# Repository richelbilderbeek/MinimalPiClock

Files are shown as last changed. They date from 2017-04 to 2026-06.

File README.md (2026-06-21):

# Minimal Pi Clock

<!-- markdownlint-disable MD013 --><!-- Table rows must be put on one line, hence 80 chars is unavoidable -->






<!-- markdownlint-enable MD013 -->

[Go to our nicely rendered website](https://richelbilderbeek.github.io/minimal_pi_clock/).

- [Contributing](docs/CONTRIBUTING.md)

## Files used by continuous integration scripts

<!-- markdownlint-disable MD013 --><!-- Table rows must be put on one line, hence 80 chars is unavoidable -->

Filename                                    |Descriptions
--------------------------------------------|--------------------------------------------------------------------------------------------------------------------------------------
[`mlc_config.json`](mlc_config.json)        |Configuration of the link checker, use `markdown-link-check --config mlc_config.json --quiet docs/**/*.md` to do link checking locally
[`.markdownlint.jsonc`](.markdownlint.jsonc)|Configuration of the Markdown linter, use `markdownlint "**/*.md"` to do markdown linting locally. The name of this file is a default name.
[`.markdownlintignore`](.markdownlintignore)|Files ignored by the Markdown linter, use `markdownlint "**/*.md"` to do markdown linting locally. The name of this file is a default name.

<!-- markdownlint-enable MD013 -->

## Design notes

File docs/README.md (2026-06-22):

# Minimal Pi Clock

The Minimal Pi Clock is
[one of my machines](https://github.com/richelbilderbeek/Machines)
that uses (the programmable chip of an) Arduino.

It's an Arduino project for a clock that beeps at pi o'clock PM
(i.e. 3:14 PM or 15:14). It can easily be made to beep at 3:14 AM
for the purists :-)

- [Photos](photos/README.md)
- [Parts list](parts_list/README.md)
- [Code](src/README.md)
- [Schematic](schematic/README.md)
- [Casing](casing/README.md)
- [FAQ](faq.md)

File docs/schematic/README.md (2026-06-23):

# Schematics

- [The Fritzing file](minimal_pi_clock.fzz)

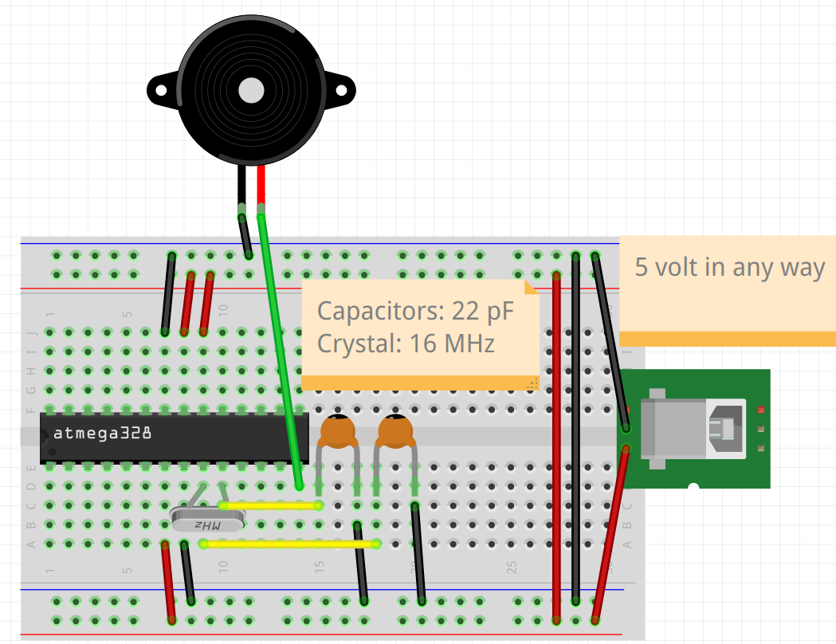
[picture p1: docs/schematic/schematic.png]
The Minimal Pi Clock schematic


Build the schematic as such,
using the chip with The Minimal Pi Clock
program on it.

??? question "In which orientation must I have the chip?"

    The notch of the chip must be at the left:

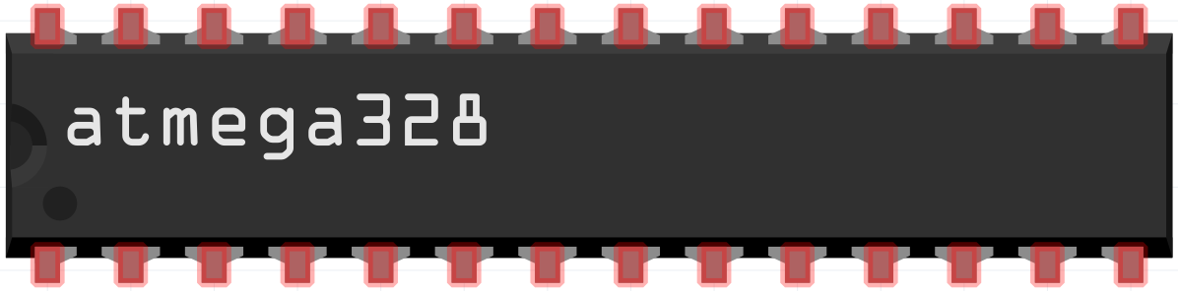
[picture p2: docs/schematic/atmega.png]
The notch of the chip must be at the left
    

    > The notch of the chip must be at the left.

??? question "Can you show the wiring of the chip as a table?"

    Yes.

    Here is an equivalent table:

    Pin  |1  |2  |3  |4  |5  |6  |7  |8  |9  |10 |11 |12 |13 |14
    -----|---|---|---|---|---|---|---|---|---|---|---|---|---|---
    Upper|.  |.  |.  |.  |.  |.  |GND|5V |5V |.  |.  |.  |.  |.
    Lower|.  |.  |.  |.  |.  |.  |5V |GND|X1 |X2 |.  |.  |.  |P

    - `GND`: to ground
    - `5V`: to 5 volt
    - `X1`: to a capacitor and crystal
    - `X2`: to (another) capacitor and (the same) crystal
    - `P`: to plus of piezo

??? question "What does '5 Volts in any way' mean?"

    Where the schematic states '5 Volts in any way',
    this means any reasonable way to provide 5 volts
    for the machine.

    In this example, a USB-B female is shown,
    but any USB connector can be used.

??? question "Can I use other electric potenials than 5V?"

    Yes.

    The range of the chip is wider than 5 volts.

Upon powering this, the buzzer will go off for
a little more than three seconds.

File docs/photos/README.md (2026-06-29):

# Minimal Pi Clock pictures

The Minimal Pi Clock can look many different ways.

## 2017

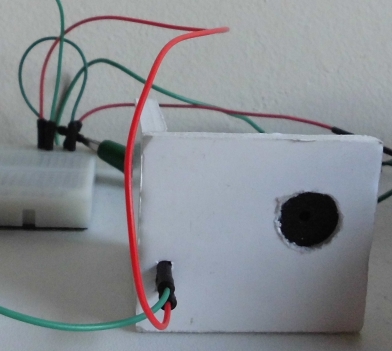
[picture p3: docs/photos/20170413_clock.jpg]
Minimal Pi Clock in 2017, full picture


> Minimal Pi Clock, front view. The machine was powered by the Arduino
> 5V and GND pins.

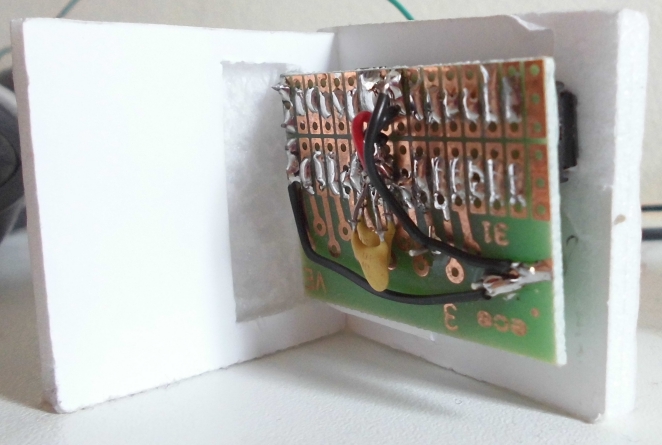
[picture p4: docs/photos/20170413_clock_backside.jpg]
Minimal Pi Clock in 2017, backside view


> Minimal Pi Clock, back view

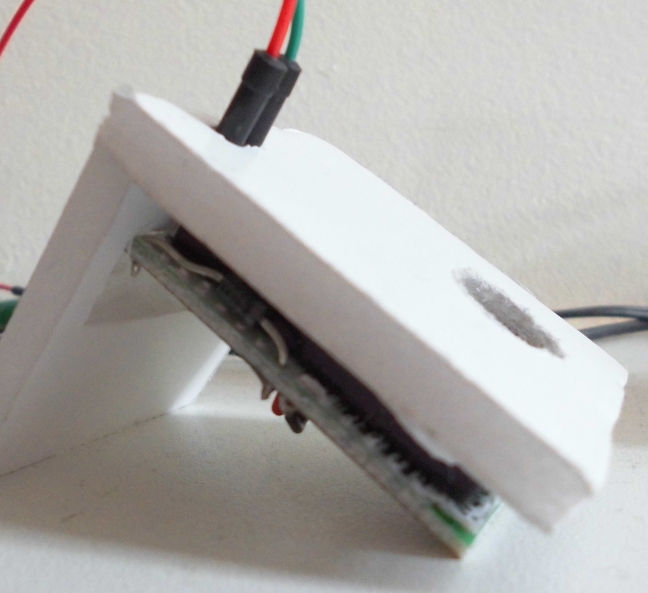
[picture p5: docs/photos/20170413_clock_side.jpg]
Minimal Pi Clock in 2017, side view


> Minimal Pi Clock, side view

## 2019

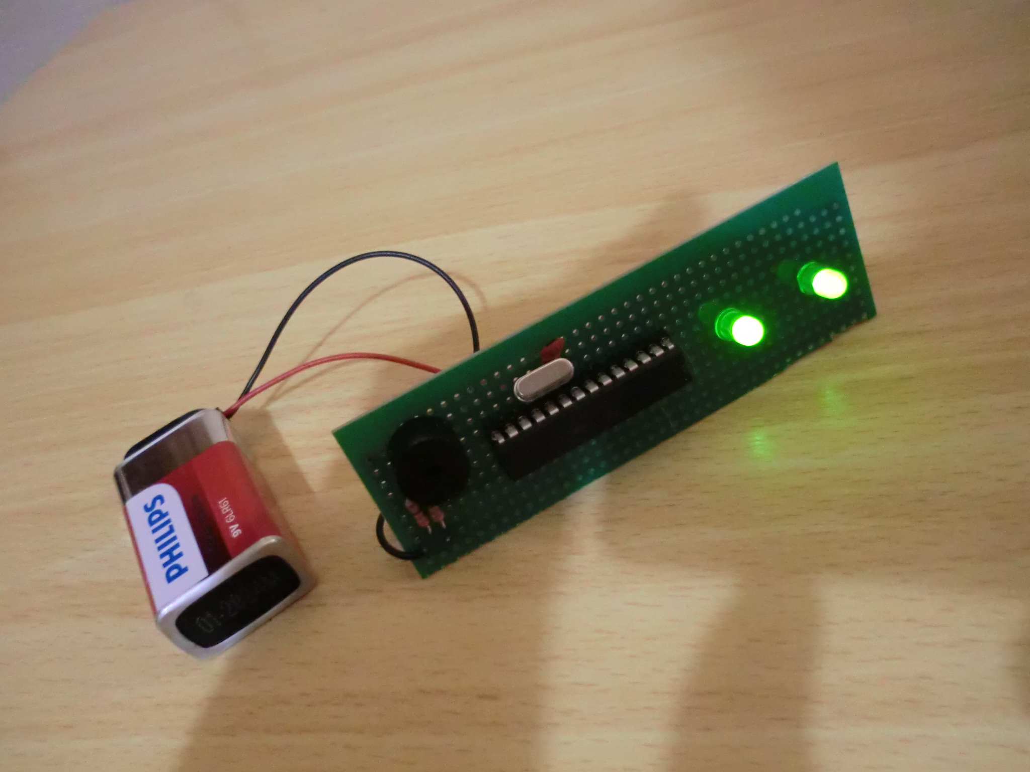
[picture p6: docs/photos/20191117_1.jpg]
Minimal Pi Clock in 2019, PCB front view


> PCB is ready, front view

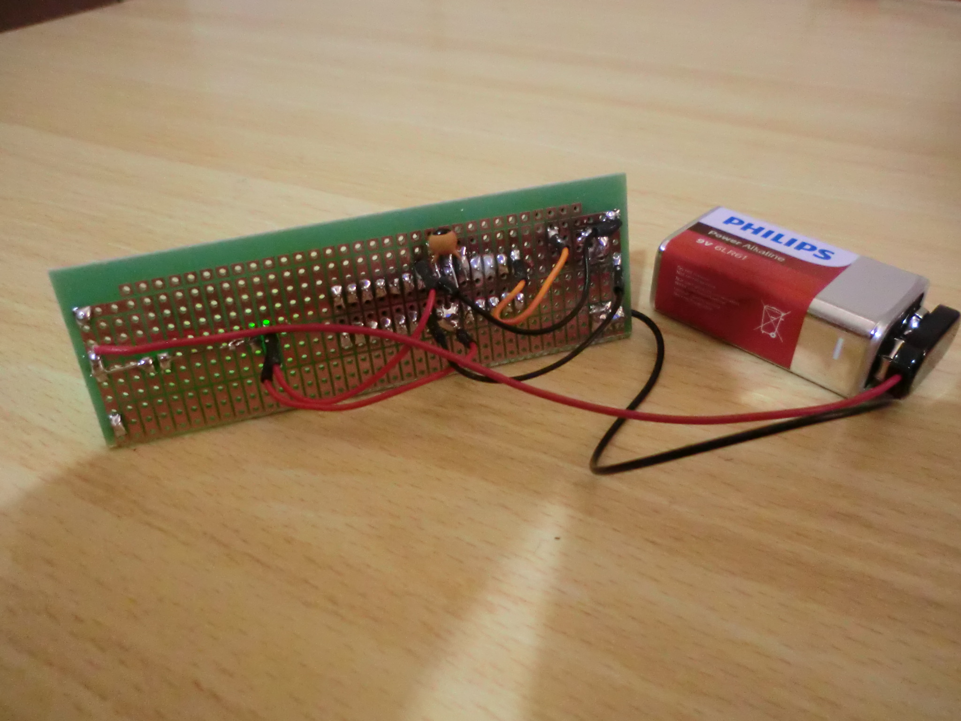
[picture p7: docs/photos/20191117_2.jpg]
Minimal Pi Clock in 2019, PCB back view


> PCB is ready, back view

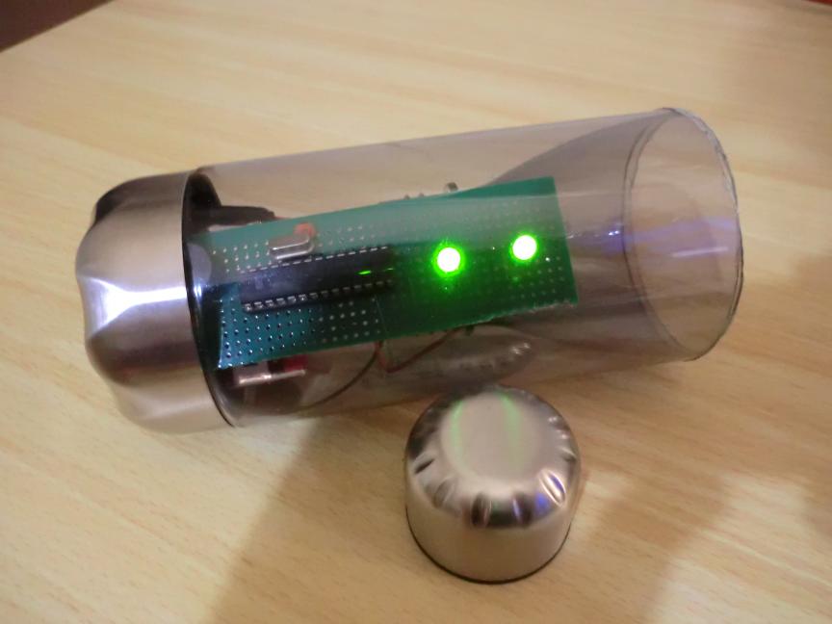
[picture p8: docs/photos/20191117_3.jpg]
Minimal Pi Clock in 2019, in casing, front view


> Minimal Pi Clock, front view

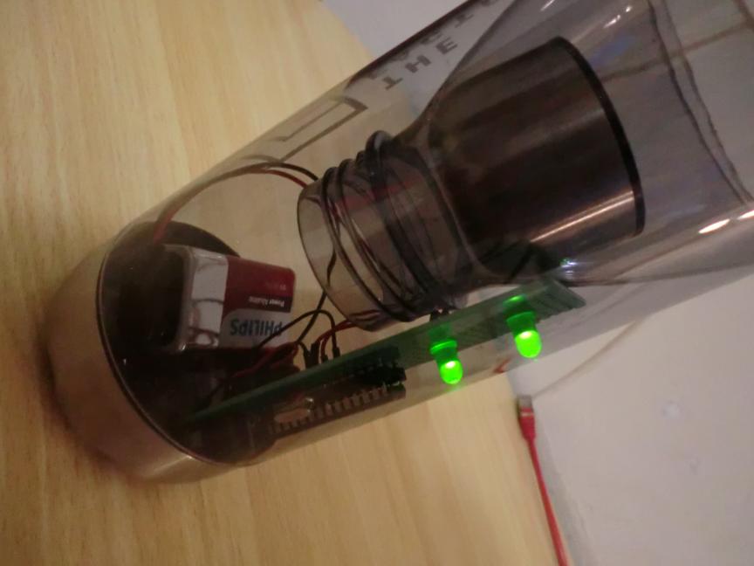
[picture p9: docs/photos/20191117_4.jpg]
Minimal Pi Clock in 2019, in casing, back view


> Minimal Pi Clock, back view

## 2026

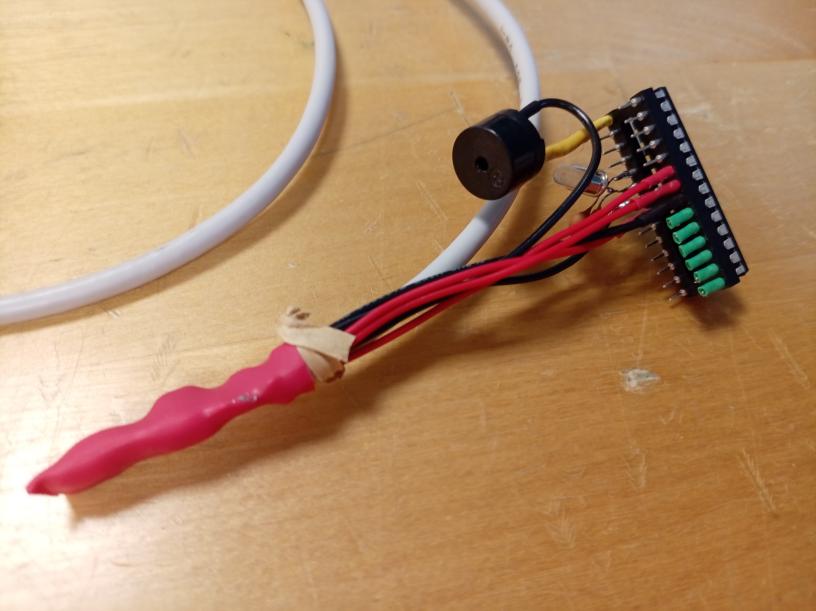
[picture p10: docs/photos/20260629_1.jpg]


> Minimal Pi Clock, point-to-point soldering

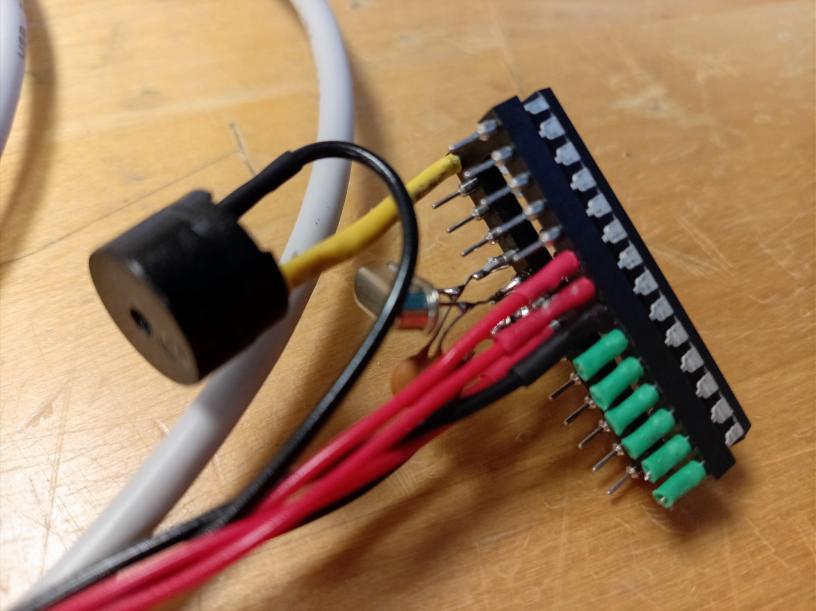
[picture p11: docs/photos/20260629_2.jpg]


> Minimal Pi Clock, point-to-point soldering

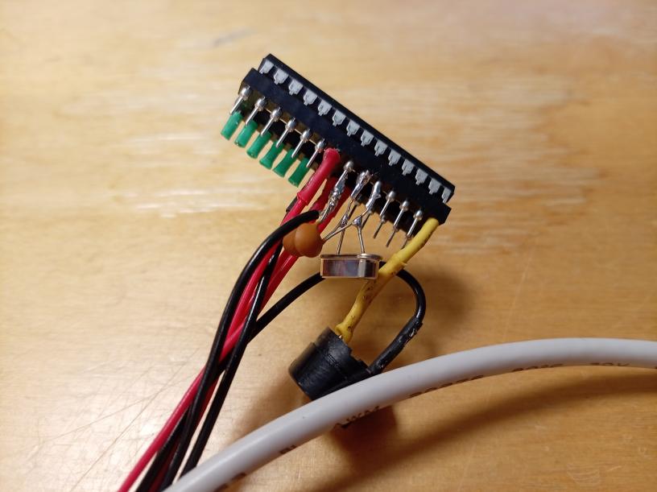
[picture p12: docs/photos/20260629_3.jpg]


> Minimal Pi Clock, point-to-point soldering

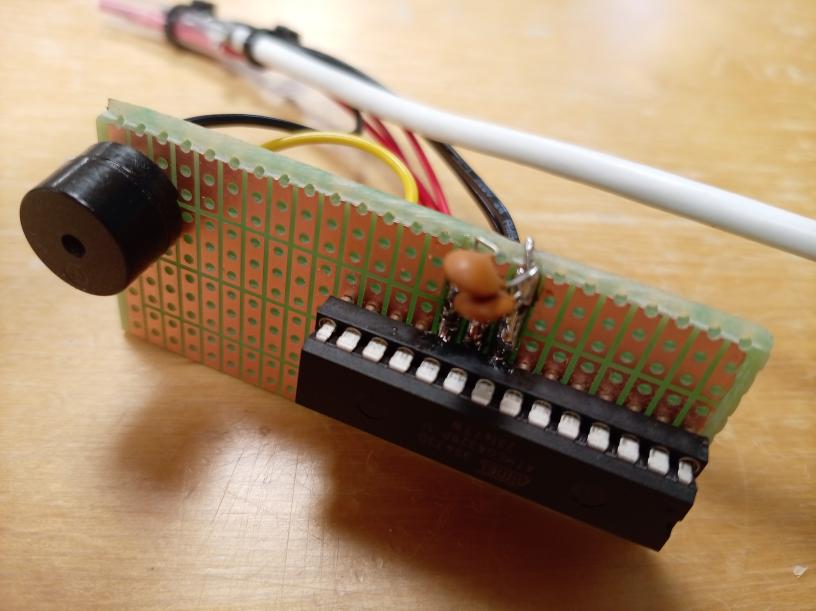
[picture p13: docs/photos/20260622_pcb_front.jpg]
Minimal Pi Clock in 2026, PCB front view


> PCB is ready, front view

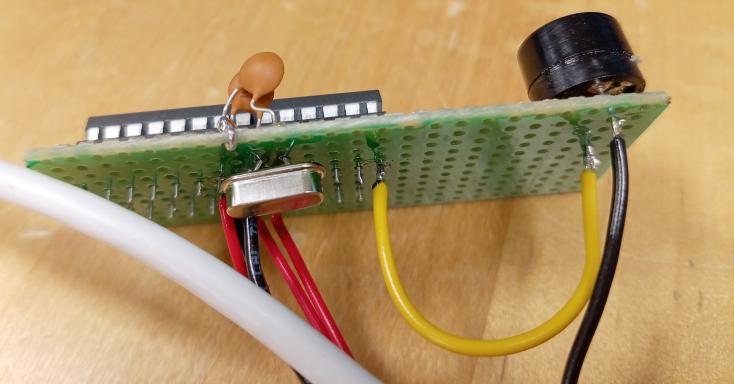
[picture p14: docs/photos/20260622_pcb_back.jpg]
Minimal Pi Clock in 2026, PCB back view


> PCB is ready, back view

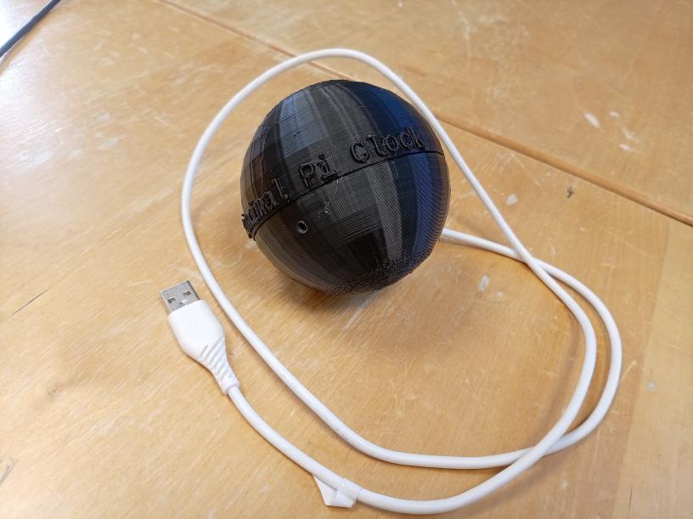
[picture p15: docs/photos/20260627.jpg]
Minimal Pi Clock with spherical casing v0.2


> Minimal Pi Clock with spherical casing v0.2

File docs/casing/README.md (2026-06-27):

# Casing

- OpenSCAD file: [`sphere.scad`](sphere.scad)

I designed the casing in OpenSCAD:

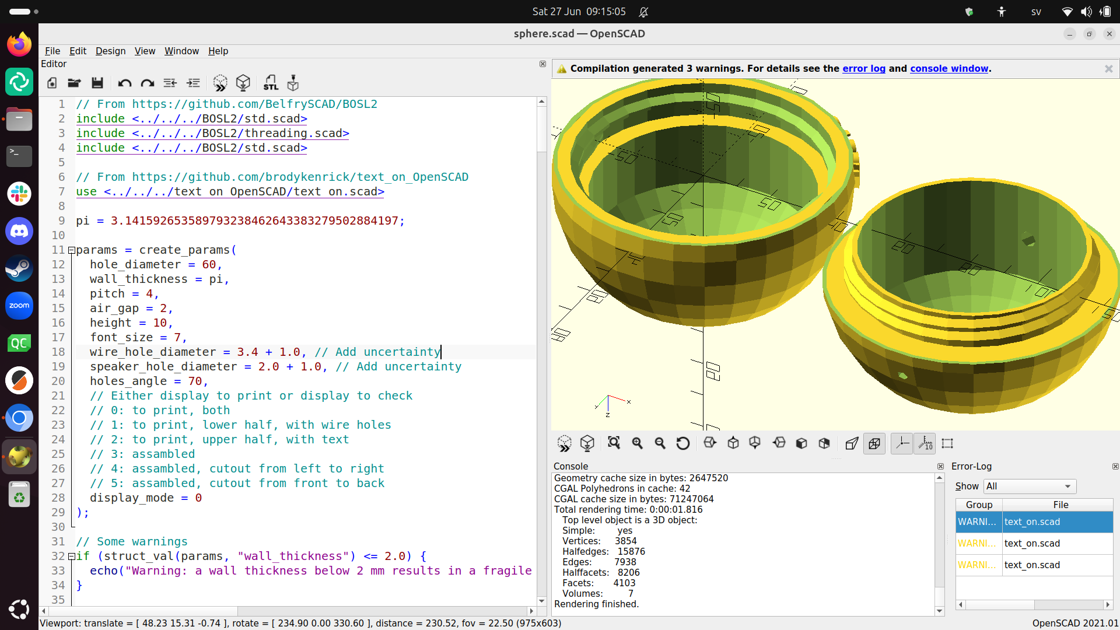
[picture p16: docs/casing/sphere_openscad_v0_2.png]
Casing v0.2, in OpenSCAD


I used two OpenSCAD libraries:

- [BOSL2](https://github.com/BelfrySCAD/BOSL2): for the thread
- [text_on_OpenSCAD](https://github.com/brodykenrick/text_on_OpenSCAD):
  for the text on the machine

The code has multiple modes to display the casing.
There is a mode for displaying the two half-spheres side-by-side,
to have one print. This may be slower, however, than (displaying and) printing
each half seperately, as the 3D printer head needs to move between two half
spheres.

???- question "Can you give some measured print times?"

    Yes, here are measured print times:

    Shere|Printing time (mins)
    -----|--------------------
    Lower|123
    Upper|138
    Both |267

    From these numbers, we can conclude that it is shorter to print each
    half-sphere in isolation: it takes 261 mins for printing each half
    in isolation winning 6 minutes. However, in those 6 minutes
    between prints, time is lost by manually removing the printed first half
    and starting the printer to do the other half.

For historians, see [the casing's history](../casings_history/README.md)

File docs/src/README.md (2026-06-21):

# Code

- [Minimal Pi Clock source code](src.ino)

The code for the Minimal Pi Clock is
written in C++ using the Arduino IDE
and does not require any libraries.

Upload it as usual.

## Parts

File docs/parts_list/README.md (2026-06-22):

---
tags:
  - buy
  - components
  - parts
  - BOM
  - bill
  - materials
  - price
---

# Parts list

Here is the list of all the components to buy,
with an example supplier and price.

Picture                       |Name                                 |Description              |Price (SEK)
------------------------------|-------------------------------------|-------------------------|------------------------------------------------------------------------------------
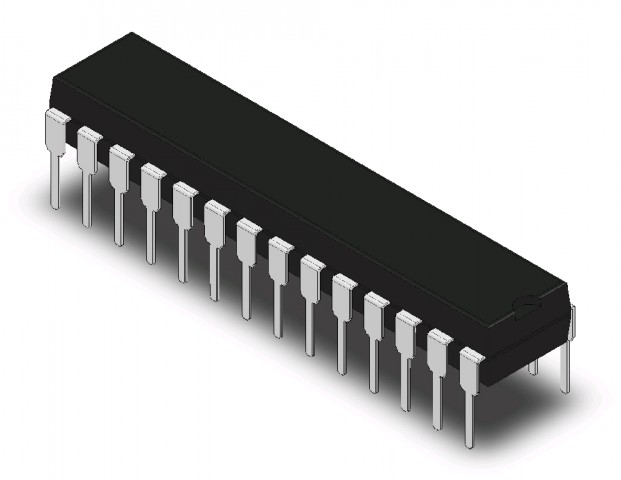
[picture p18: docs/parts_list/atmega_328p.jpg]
ATMega328P
|ATMega328P                           |The main Arduino Uno chip|[47](https://www.electrokit.com/en/atmega328p-pu-dip-28n-8-bit-mcu-flash-32k-picopower)
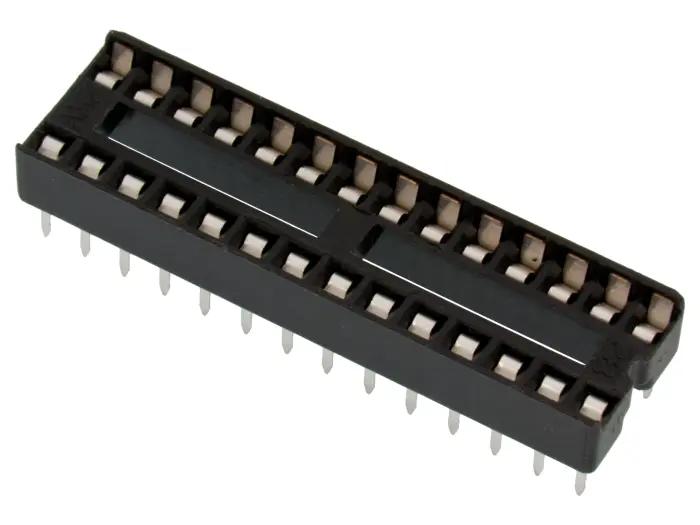
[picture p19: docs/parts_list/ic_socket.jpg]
IC socket
   |DIL socket 28-pin                    |For holding the chip     |[14](https://www.electrokit.com/en/dil-hallare-28-pin-0.3) (you need to buy 4, you need 1)
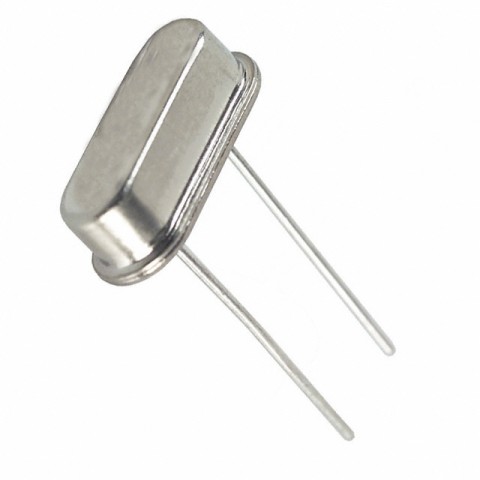
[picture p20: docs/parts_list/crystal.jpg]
Crystal
       |Crystal 16.0000 MHz HC49/S **20pF**  |Sets the clock speed     |[14](https://www.electrokit.com/kristall-16.0000-mhz-hc49/s) (you need to buy 5, you need 1)
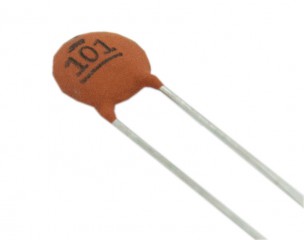
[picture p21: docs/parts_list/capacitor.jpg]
Capacitor
   |Ceramic capacitor **22pF** 50V NP0   |Stabilizes the crystal   |[12](https://www.electrokit.com/keramisk-22pf-50v-np0-2.54mm) (you need to buy 10, you need 2)
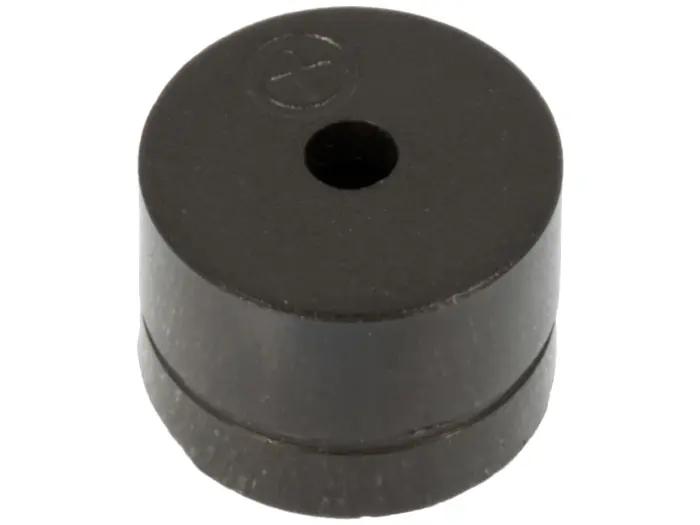
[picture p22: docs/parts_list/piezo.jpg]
Piezo
           |Passive piezobuzzer **5V** PCB       |Generates the sound      |[12](https://www.electrokit.com/piezoelement-12x8.5mm-passiv)
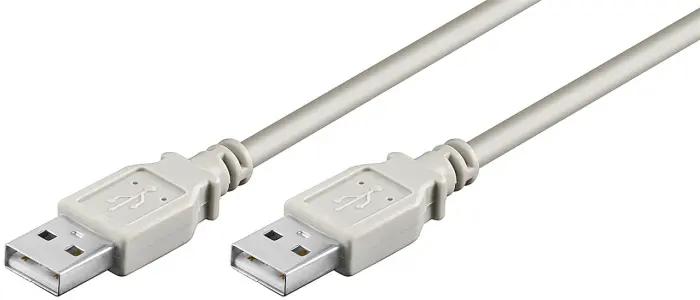
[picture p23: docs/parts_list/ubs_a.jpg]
USB-A
           |UBS-A male cable                     |To plug in the machine   |[26](https://www.electrokit.com/usb-kabel-a-hane-a-hane-1.8m) (you need to buy 1, you need half)
.                             |Shipping                             |The cost to ship         |35
.                             |Total                                |Sum of all costs         |160

??? question "Are you sponsored by the example supplier?"

    No.

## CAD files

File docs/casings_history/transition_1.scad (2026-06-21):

// Made by Claude. I, Richel, think it is quite a bad design :-/
//
// === Dimensions ===
outer_width     = 40; // mm  (X when assembled)
outer_depth     = 30; // mm  (Y when assembled)
outer_height    = 20; // mm  (Z when assembled)
wall_thickness  = 2;  // mm
inner_width     = outer_width  - wall_thickness;
inner_depth     = outer_depth  - wall_thickness;
inner_height    = outer_height - wall_thickness;

n_teeth         = 10;
teeth_air       = 0.25; // gap per tooth side, mm
piezo_diameter  = 12;   // mm
piezo_radius    = piezo_diameter / 2;
cable_diameter  = 5;    // mm
cable_radius    = cable_diameter / 2;

spacing         = 3;    // gap between unconnected panels in the flat layout

//
// Panel roles (assembled box):
//   1 = bottom   (has piezo cutout — glued first while flat, fully accessible)
//   2 = left side
//   3 = top
//   4 = right side (has cable hole at bottom edge when assembled)
//   5 = front
//   6 = back
//
// New flat layout — connected vertical strip + wings:
//
//         [5 front]       w×h
//         [3 top  ]       w×d
//   [2 L] [1 botm ] [4 R] h×d | w×d | h×d
//         [6 back ]       w×h
//
// Panels 5-3-1-6 are directly connected (share an edge, no gap).
// Panels 2 and 4 sit beside panel 1 with a small spacing gap
// (they still need teeth on that edge to lock in).
//
// Assembly order:
//   1. Glue piezo to panel 1 (bottom) while it lies flat — easy access.
//   2. Fold 5-3-1-6 strip into a U, add panel 2 and 4 as sides, lastly close.
//   3. Route cable through hole in panel 4 (right side, near bottom edge).

// -----------------------------------------------------------------------
// Helpers
// -----------------------------------------------------------------------

// Teeth along the LEFT edge of a panel (pointing left, every other slot)
module teeth_left(dx, dy, nt) {
    yt = dy / nt;
    for (i = [0 : nt/2 - 1])
        translate([-wall_thickness, i * yt * 2 + teeth_air, 0])
            cube([wall_thickness, yt - teeth_air, wall_thickness]);
}

// Teeth along the RIGHT edge
module teeth_right(dx, dy, nt) {
    yt = dy / nt;
    for (i = [0 : nt/2 - 1])
        translate([dx, yt + i * yt * 2 + teeth_air, 0])
            cube([wall_thickness, yt - teeth_air, wall_thickness]);
}

// Teeth along the TOP edge (pointing up)
module teeth_top(dx, dy, nt) {
    xt = dx / nt;
    for (i = [0 : nt/2 - 1])
        translate([i * xt * 2 + teeth_air, dy, 0])
            cube([xt - teeth_air, wall_thickness, wall_thickness]);
}

// Teeth along the BOTTOM edge (pointing down)
module teeth_bottom(dx, dy, nt) {
    xt = dx / nt;
    for (i = [0 : nt/2 - 1])
        translate([xt + i * xt * 2 + teeth_air, -wall_thickness, 0])
            cube([xt - teeth_air, wall_thickness, wall_thickness]);
}

// -----------------------------------------------------------------------
// Generic panel: face + selective teeth on each of the 4 edges.
// Flags: tl=left, tr=right, tt=top, tb=bottom  (1=draw teeth, 0=plain edge)
// -----------------------------------------------------------------------
module panel(dx, dy, nt, tl=1, tr=1, tt=1, tb=1) {
    cube([dx, dy, wall_thickness]);
    if (tl) teeth_left(dx, dy, nt);
    if (tr) teeth_right(dx, dy, nt);
    if (tt) teeth_top(dx, dy, nt);
    if (tb) teeth_bottom(dx, dy, nt);
}

// -----------------------------------------------------------------------
// Panel 1 — bottom, with piezo mounting recess + through-hole
// Piezo sits centred in X, near the front in Y (accessible, away from cable)
// -----------------------------------------------------------------------
module panel_bottom() {
    difference() {
        panel(inner_width, inner_depth, n_teeth, tl=1, tr=1, tt=0, tb=0);
        // Recess ring: lets the piezo lip sit flush
        translate([inner_width/2, inner_depth/4, wall_thickness - 0.5])
            cylinder(h=1.5, r=piezo_radius + teeth_air, $fn=64);
        // Through-hole: sound can pass / wire can be routed if needed
        translate([inner_width/2, inner_depth/4, -1])
            cylinder(h=wall_thickness + 2, r=piezo_radius - 1, $fn=64);
    }
}

// -----------------------------------------------------------------------
// Panel 4 — right side, cable hole near the bottom-assembled edge
// -----------------------------------------------------------------------
module panel_right() {
    difference() {
        panel(inner_height, inner_depth, n_teeth, tl=1, tr=1, tt=0, tb=0);
        // Cable hole: centred in depth, close to the bottom edge (y≈cable_radius+wt)
        translate([inner_height/2, inner_depth/2, -1])
            cylinder(h=wall_thickness + 2, r=cable_radius + teeth_air, $fn=32);
    }
}

// -----------------------------------------------------------------------
// Flat layout
//
// The strip 5→3→1→6 is laid out top-to-bottom, connected (no gap).
// Panel widths in the strip direction:
//   5 (front): inner_height tall
//   3 (top)  : inner_depth tall
//   1 (botm) : inner_depth tall
//   6 (back) : inner_height tall
//
// Panels 2 (left) and 4 (right) sit beside panel 1 with spacing.
// -----------------------------------------------------------------------

// Origin of the strip: panel 5 starts at (0,0)
p5_x = 0;
p5_y = 0;

p3_x = p5_x;
p3_y = p5_y - inner_depth;        // directly below panel 5 (front)
// (no gap — shared edge)

p1_x = p3_x;
p1_y = p3_y - inner_depth;        // directly below panel 3 (top)

p6_x = p1_x;
p6_y = p1_y - inner_height;       // directly below panel 1 (bottom)

// Left panel (2) beside panel 1
p2_x = p1_x - inner_height - spacing;
p2_y = p1_y;

// Right panel (4) beside panel 1
p4_x = p1_x + inner_width + spacing;
p4_y = p1_y;

//
//        [5 front  ] — top of strip, free top/left/right teeth
//        [3 top    ] — free left/right teeth
//  [2 L] [1 bottom ] [4 R]
//        [6 back   ] — free left/right/bottom teeth
//

// --- Panel 5: front  (w × h), free on left, right, top ---
translate([p5_x, p5_y, 0])
    panel(inner_width, inner_height, n_teeth, tl=1, tr=1, tt=1, tb=0);

// --- Panel 3: top  (w × d), free on left, right ---
translate([p3_x, p3_y, 0])
    panel(inner_width, inner_depth, n_teeth, tl=1, tr=1, tt=0, tb=0);

// --- Panel 1: bottom (w × d), piezo cutout, free on left, right ---
translate([p1_x, p1_y, 0])
    panel_bottom();

// --- Panel 6: back (w × h), free on left, right, bottom ---
translate([p6_x, p6_y, 0])
    panel(inner_width, inner_height, n_teeth, tl=1, tr=1, tt=0, tb=1);

// --- Panel 2: left side (h × d), free on left, top, bottom ---
translate([p2_x, p2_y, 0])
    panel(inner_height, inner_depth, n_teeth, tl=1, tr=0, tt=1, tb=1);

// --- Panel 4: right side (h × d), cable hole, free on right, top, bottom ---
translate([p4_x, p4_y, 0])
    panel_right();

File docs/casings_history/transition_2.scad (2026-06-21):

// Made by Claude. I, Richel, think it is quite a bad design :-/
//
// ============================================================
// Piezo casing — foldable flat-pack with living hinges
// ============================================================
//
// Layout (flat):
//
//              [3 top/lid]
//                  |
//       [2 left]--[1 bottom]--[4 right]
//                  |               |
//              [5 front]       (cable hole)
//                  |
//              [6 back — piezo hole]
//
// Panels 1,2,4,5,6 are connected via living hinges (thin flex lines).
// Panel 3 (lid) is a separate piece with finger joints on all 4 edges.
// Panels 2 and 4 also have finger joints on their free top edge
// so they lock to the lid.
//
// Assembly:
//   1. Glue piezo disc into panel 6 (back) while flat — full access.
//   2. Fold 2, 4, 5, 6 up 90° along hinge lines.
//   3. The corner finger joints of 2/4 with 5/6 interlock.
//   4. Thread cable through hole in panel 4, glue panel 4 corner joints.
//   5. Drop lid (panel 3) onto the open top, press finger joints home.
//
// ============================================================

// === Parameters ===
outer_width    = 40;   // X dimension of assembled box
outer_depth    = 30;   // Y dimension
outer_height   = 20;   // Z dimension
wall_t         = 2;    // wall thickness

// Living hinge
hinge_t        = 0.4;  // thickness of flex zone (fraction of wall_t)
hinge_w        = 1.5;  // width of the flex zone along the fold line

// Finger joints
n_teeth        = 6;    // number of teeth per edge (keep even)
teeth_air      = 0.2;  // clearance per side

// Cutouts
piezo_d        = 12;
cable_d        = 5;

// Layout spacing (only between panel 3 and the cross)
spacing        = 4;

// Derived
iw = outer_width  - wall_t;
id = outer_depth  - wall_t;
ih = outer_height - wall_t;

// ============================================================
// MODULES
// ============================================================

// --- Finger teeth along an edge ---
// axis: "x" = teeth point in X dir (along a Y-length edge)
//       "y" = teeth point in Y dir (along an X-length edge)
// side: which side the teeth stick out toward (+1 or -1)
// length: length of the edge
// offset_parity: 0=teeth on even slots, 1=teeth on odd slots
//   (use opposite parities on mating edges so they interlock)

module teeth_x(length, side, parity) {
    // teeth stick out in X, edge runs in Y
    t = length / n_teeth;
    for (i = [0 : n_teeth - 1]) {
        if ((i % 2) == parity)
            translate([
                side > 0 ? 0 : -wall_t,
                i * t + teeth_air,
                0
            ])
            cube([wall_t, t - 2*teeth_air, wall_t]);
    }
}

module teeth_y(length, side, parity) {
    // teeth stick out in Y, edge runs in X
    t = length / n_teeth;
    for (i = [0 : n_teeth - 1]) {
        if ((i % 2) == parity)
            translate([
                i * t + teeth_air,
                side > 0 ? 0 : -wall_t,
                0
            ])
            cube([t - 2*teeth_air, wall_t, wall_t]);
    }
}

// --- Living hinge line ---
// Creates a thin groove across the full width of the panel
// so it can fold. Groove is cut from the top surface.
// dir: "x" = groove runs in X (fold along X axis)
//      "y" = groove runs in Y
// panel_w, panel_d: panel extents in X and Y
// pos: position of hinge along the other axis
module hinge_groove_x(panel_w, pos) {
    translate([0, pos - hinge_w/2, wall_t - hinge_t])
        cube([panel_w, hinge_w, hinge_t + 0.01]);
}
module hinge_groove_y(panel_d, pos) {
    translate([pos - hinge_w/2, 0, wall_t - hinge_t])
        cube([hinge_w, panel_d, hinge_t + 0.01]);
}

// ============================================================
// PANEL 1 — bottom (iw × id)
// Hinges to: 2 (left edge, x=0), 4 (right edge, x=iw),
//            5 (front edge, y=0), 6 (back edge, y=id)
// No finger joints on its own edges (hinge takes care of it).
// ============================================================
module panel_bottom() {
    difference() {
        cube([iw, id, wall_t]);
        // living hinges
        hinge_groove_y(id, 0);          // left edge hinge
        hinge_groove_y(id, iw);         // right edge hinge
        hinge_groove_x(iw, 0);          // front edge hinge
        hinge_groove_x(iw, id);         // back edge hinge
    }
}

// ============================================================
// PANEL 2 — left side (ih × id), attached to panel 1 left edge
// Free top edge: finger joints (locks to lid)
// Left/right edges: become corners — finger joints with 5 and 6
// Bottom edge: hinge (already on panel 1)
// ============================================================
module panel_left() {
    union() {
        difference() {
            cube([ih, id, wall_t]);
            // No grooves needed here — hinge is on panel 1
        }
        // Top edge teeth (mate with lid panel 3, parity 0)
        teeth_y(ih, +1, 0);
        // Left edge teeth (mate with panel 5 front, parity 0)
        teeth_x(id, -1, 0);
        // Right edge teeth (mate with panel 6 back, parity 0)
        teeth_x(id, +1, 0);
    }
}

// ============================================================
// PANEL 4 — right side (ih × id), attached to panel 1 right edge
// Cable hole centred in the panel (easy to route wire before closing lid)
// Free top edge: finger joints (locks to lid)
// Left/right edges: finger joints with 5 and 6
// ============================================================
module panel_right() {
    difference() {
        union() {
            cube([ih, id, wall_t]);
            // Top edge teeth (mate with lid, parity 0)
            teeth_y(ih, +1, 0);
            // Left edge (mates with panel 5)
            teeth_x(id, -1, 0);
            // Right edge (mates with panel 6)
            teeth_x(id, +1, 0);
        }
        // Cable hole — centred, near the bottom of the assembled wall
        // (bottom = the hinge side = y=0 in flat layout)
        translate([ih/2, id * 0.25, -1])
            cylinder(h=wall_t+2, r=cable_d/2 + teeth_air, $fn=32);
    }
}

// ============================================================
// PANEL 5 — front (iw × ih), attached to panel 1 front edge
// Left/right edges: finger joints with 2 and 4 (parity 1, mates 0)
// Top edge: finger joints with lid (parity 0)
// Bottom edge: hinge (on panel 1)
// ============================================================
module panel_front() {
    union() {
        cube([iw, ih, wall_t]);
        // Top edge (mates with lid, parity 0)
        teeth_y(iw, +1, 0);
        // Left edge (mates with panel 2 right side, parity 1 → interlocks with parity 0)
        teeth_x(ih, -1, 1);
        // Right edge (mates with panel 4 left side, parity 1)
        teeth_x(ih, +1, 1);
    }
}

// ============================================================
// PANEL 6 — back (iw × ih), attached to panel 1 back edge
// Piezo hole: centred, full access while flat
// Left/right edges: finger joints with 2 and 4 (parity 1)
// Top edge: finger joints with lid (parity 0)
// ============================================================
module panel_back() {
    difference() {
        union() {
            cube([iw, ih, wall_t]);
            // Top edge (mates with lid, parity 0)
            teeth_y(iw, +1, 0);
            // Left edge (mates with panel 2, parity 1)
            teeth_x(ih, -1, 1);
            // Right edge (mates with panel 4, parity 1)
            teeth_x(ih, +1, 1);
        }
        // Piezo hole — centred in the panel
        translate([iw/2, ih/2, -1])
            cylinder(h=wall_t+2, r=piezo_d/2 + teeth_air, $fn=64);
    }
}

// ============================================================
// PANEL 3 — lid (iw × id), separate piece
// All 4 edges have finger joints (parity 1, mates parity 0 on walls)
// ============================================================
module panel_lid() {
    union() {
        cube([iw, id, wall_t]);
        // All four edges, parity 1 (mates with parity 0 on walls)
        teeth_y(iw, -1, 1);           // front edge (mates panel 5)
        teeth_y(iw, +1, 1);           // back edge  (mates panel 6)
        teeth_x(id, -1, 1);           // left edge  (mates panel 2)
        teeth_x(id, +1, 1);           // right edge (mates panel 4)
    }
}

// ============================================================
// FLAT LAYOUT
//
//     [3 lid]   — above the cross, with spacing
//
//         [6 back ]
//  [2 L]  [1 botm ]  [4 R]
//         [5 front]
//
// ============================================================

// Panel 1 origin (centre of cross)
p1x = ih + wall_t;   // leave room for panel 2 to the left
p1y = ih + wall_t;   // leave room for panel 5 below

// Panel 5 (front) — below panel 1
translate([p1x, p1y - ih - wall_t, 0])  panel_front();

// Panel 6 (back) — above panel 1
translate([p1x, p1y + id + wall_t, 0])  panel_back();
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

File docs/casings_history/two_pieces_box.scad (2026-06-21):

// This design has replaced its joints by actual connections

outer_width = 40; // mm
outer_depth = 30; // mm
outer_height = 80; // mm
wall_thickness = 2; // mm
inner_width = outer_width - (2 * wall_thickness); // mm
inner_depth = outer_depth - (2 * wall_thickness); // mm
inner_height = outer_height - (2 * wall_thickness); // mm
n_teeth = 10;
x_teeth_length = inner_width / n_teeth;
y_teeth_length = inner_depth / n_teeth;
z_teeth_length = inner_height/ n_teeth;
piezo_diameter = 12; // mm
piezo_radius = piezo_diameter  / 2; // mm
cable_diameter = 5; // mm
cable_radius = cable_diameter / 2; // mm

// The teeth need some air between them.
// This is the amount of space that each tooth get shorten
// with at each side
teeth_air = 0.25; // mm

spacing = 1; // Spacing between the parts, mm


// Creates the hollow cube
module create_hollow_cube() {
  difference() {
    cube([outer_width,outer_depth,outer_height]);
    translate([wall_thickness,wall_thickness,wall_thickness])
      cube([inner_width,inner_depth,inner_height]);
  }
}

// The hollow cube with the top part removed. No teeth joint yet
module create_open_cube() {
  difference() {
    create_hollow_cube();
    translate([0, 0, outer_height - wall_thickness])
      cube([outer_width,outer_depth,wall_thickness]);
  }
}

create_open_cube();

/*
module create_top_piece() {
  cube([outer_width,outer_depth,wall_thickness], center = true);
}


translate([0, 0, outer_height / 2 + spacing + spacing])
  create_top_piece();

create_hollow_cube();



/*

part_1_x = -outer_width - outer_depth;
part_1_y = -outer_depth / 2;

part_2_x = part_1_x + outer_width + wall_thickness + spacing;
part_2_y = part_1_y;

part_3_x = part_2_x + outer_height + wall_thickness + spacing;
part_3_y = part_2_y;

part_4_x = part_3_x + outer_width + wall_thickness + spacing;
part_4_y = part_3_y;

part_5_x = part_3_x;
part_5_y = part_3_y + outer_depth + wall_thickness + spacing;

part_6_x = part_3_x;
part_6_y = part_3_y - (outer_depth / 2) - (outer_height / 2) - (3 * wall_thickness) - spacing;

//
//        +--+  +--+  +--+
//        |  |  |  |  |  |
//        +..+--+..+--+..+--+--+
//        |                 .  |
//     +--+                 +--+
//     |  .                 |   
//     +--+                 +--+
//        |                 .  |
//     +--+                 +--+
//     |  .                 |
//     +--+--+..+--+..+--+..+
//           |  |  |  |  |  |
//           +--+  +--+  +--+
//


module draw_piece(
  part_x,
  part_y,
  inner_dx,
  inner_dy,
  n_teeth
) {
  translate([part_x, part_y, 0])
    cube([inner_dx, inner_dy, wall_thickness]);

  x_teeth_length = inner_dx / n_teeth;
  y_teeth_length = inner_dy / n_teeth;

  // Left teeth
  for (i = [0:n_teeth/2-1])
    translate([part_x, part_y, 0])
      translate([-wall_thickness, i * y_teeth_length  * 2,0])
        translate([0, teeth_air, 0])
          cube([wall_thickness,y_teeth_length - teeth_air,wall_thickness]);
  // Right teeth
  for (i = [0:n_teeth/2-1])
    translate([part_x, part_y, 0])
      translate([inner_dx, y_teeth_length + (i * y_teeth_length  * 2),0])
        translate([0, teeth_air, 0])
          cube([wall_thickness,y_teeth_length - teeth_air,wall_thickness]);
  // Top, between 5 and 1
  for (i = [0:n_teeth/2-1])
    translate([part_x, part_y, 0])
      translate([0 + (i * x_teeth_length  * 2), inner_dy, 0])
        translate([teeth_air, 0, 0])
          cube([x_teeth_length - teeth_air, wall_thickness,wall_thickness]);
  // Bottom teeth, between 1 and 6 
  for (i = [0:n_teeth/2-1])
    translate([part_x, part_y, 0])
      translate([x_teeth_length + (i * x_teeth_length  * 2), -wall_thickness,0])
        translate([teeth_air, 0, 0])
          cube([x_teeth_length - teeth_air, wall_thickness, wall_thickness]);

}


//     +-+
//     |5|
// +-+-+-+-+
// |1|2|3|4|
// +-+-+-+-+
//     |6|
//     +-+

draw_piece(
  part_1_x, // part_x 
  part_1_y,  // part_y
  inner_width, // inner_dx
  inner_depth, // inner_dy
  n_teeth // n_teeth
);

draw_piece(
  part_2_x, // part_x 
  part_2_y,  // part_y
  inner_height, // inner_dx
  inner_depth, // inner_dy
  n_teeth // n_teeth
);


difference() {
  union() {
    draw_piece(
      part_3_x, // part_x 
      part_3_y,  // part_y
      inner_width, // inner_dx
      inner_depth, // inner_dy
      n_teeth // n_teeth
    );
  }

  translate([part_3_x + piezo_radius + wall_thickness, part_3_y + piezo_radius + wall_thickness, 0.5])
    cylinder(10, (piezo_diameter / 2) + (teeth_air * 2), (piezo_diameter / 2) + (teeth_air * 2));
  translate([part_3_x + piezo_radius + wall_thickness, part_3_y + piezo_radius + wall_thickness, -5])
    cylinder(10, piezo_radius - (teeth_air * 2), piezo_radius - (teeth_air * 2));
}

difference() {
  union() {
    draw_piece(
      part_4_x, // part_x 
      part_4_y,  // part_y
      inner_height, // inner_dx
      inner_depth, // inner_dy
      n_teeth // n_teeth
    );
  }
  translate([part_4_x + cable_radius + (inner_height / 4) + wall_thickness, part_4_y + cable_radius + (inner_depth / 2) + wall_thickness, -5])
    cylinder(10, cable_radius + (teeth_air * 2), cable_radius + (teeth_air * 2));

}

draw_piece(
  part_5_x, // part_x 
  part_5_y,  // part_y
  inner_width, // inner_dx
  inner_height, // inner_dy
  n_teeth // n_teeth
);


draw_piece(
  part_6_x, // part_x 
  part_6_y,  // part_y
  inner_width, // inner_dx
  inner_height, // inner_dy
  n_teeth // n_teeth
);


*/

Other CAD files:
docs/casing/sphere.scad
docs/casings_history/six_pieces_box.scad

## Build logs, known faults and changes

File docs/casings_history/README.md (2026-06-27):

# Casing's history

Here is the history of [the casing](README.md)
used in this machine.

## Six pieces box

The 'six pieces box' was my first idea
and my first real casing design, in OpenSCAD:

- [six_pieces_box.scad](six_pieces_box.scad)

I wanted a design without scaffolding, hence I opted
to glue to pieces together.

The first prints resulted in six pieces that did not fit together:

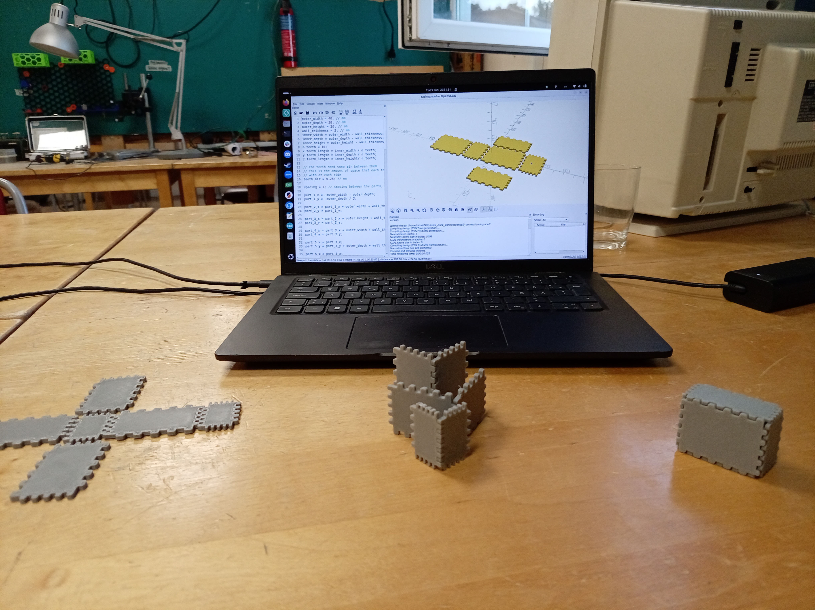
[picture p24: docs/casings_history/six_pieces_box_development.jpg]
Six pieces box in development


After adding an air gap, the pieces fit together well enough to form a box:

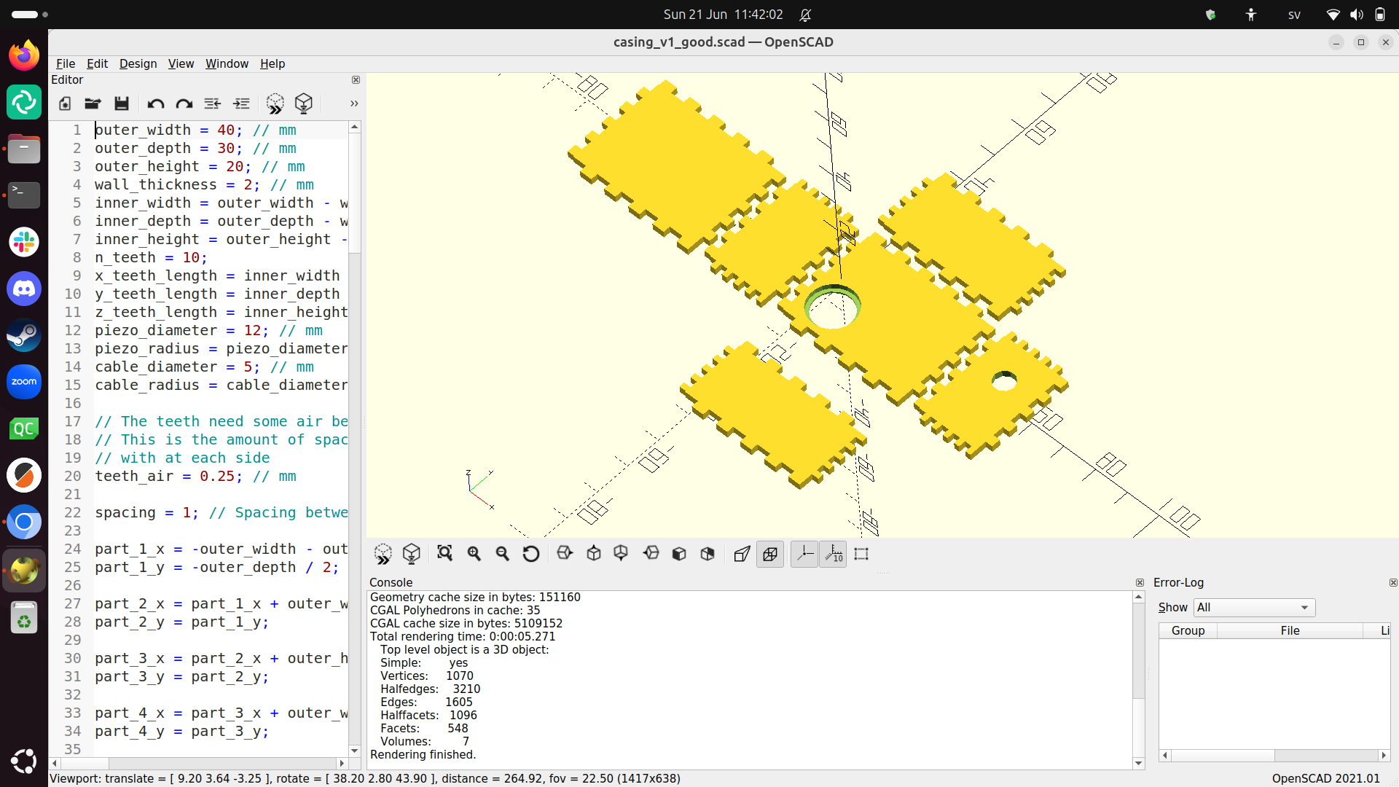
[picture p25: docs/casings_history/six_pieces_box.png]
Six pieces box


I was happy I was able to create this box.
However, I was unhappy with its design, as it involved too much glue
and the glue available to me was not strong enough.

I realized that
I can instead go for an open box design, where only a
lid needs to be conneced to the box-except-lid.
I decided to transition to this two pieces box design.

## Two pieces box

Instead of glueing together the six pieces,
I realized I could print 5 out of 6 pieces as one single piece
without scaffolding.

I first tried to create such a two pieces box
using Claude. It did not work out well:

- [transition_1.scad](transition_1.scad)

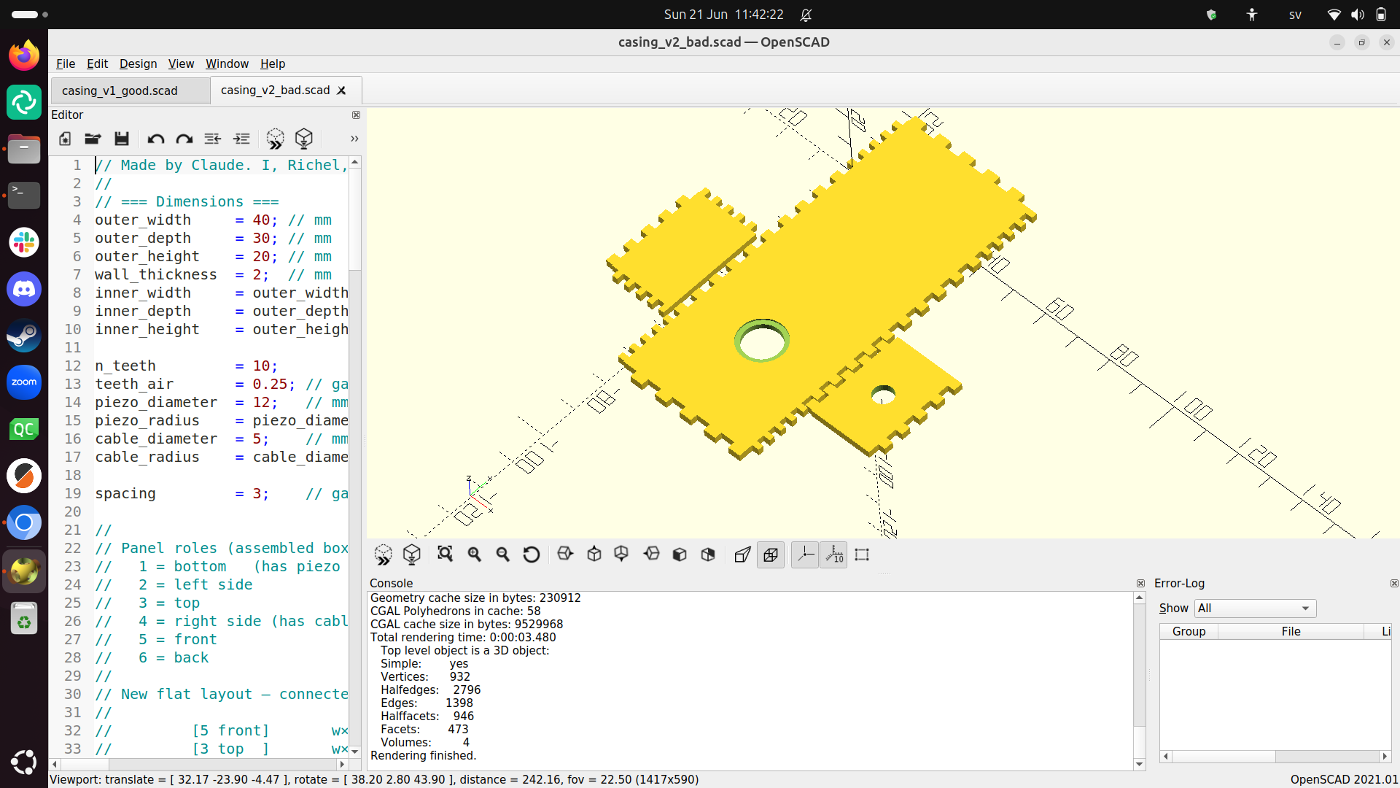
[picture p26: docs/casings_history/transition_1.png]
Transition 1


- [transition_2.scad](transition_2.scad)

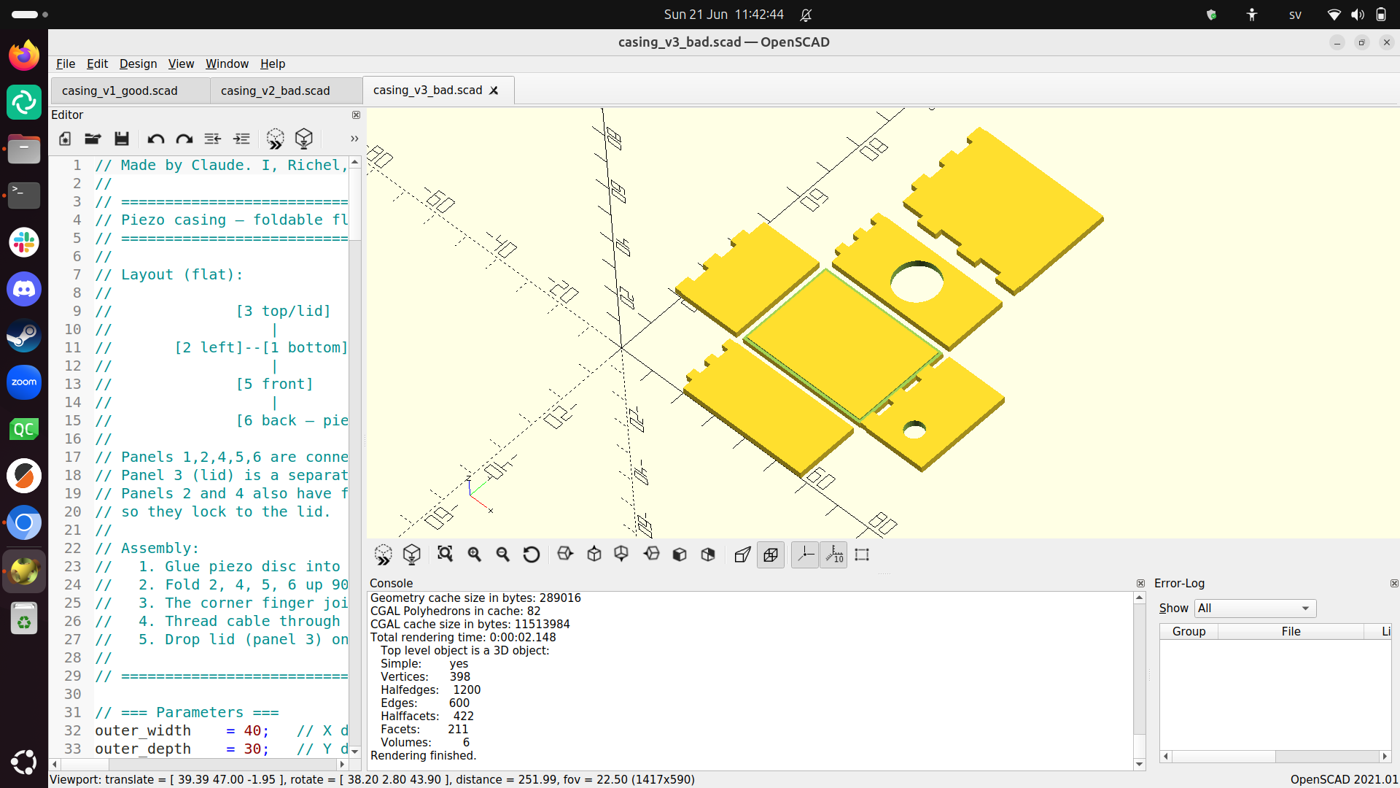
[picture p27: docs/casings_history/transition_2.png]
Transition 2


Realizing Claude does not understand OpenSCAD well enough,
I designed part of this design hand instead.

- [two_pieces_box.scad](two_pieces_box.scad)

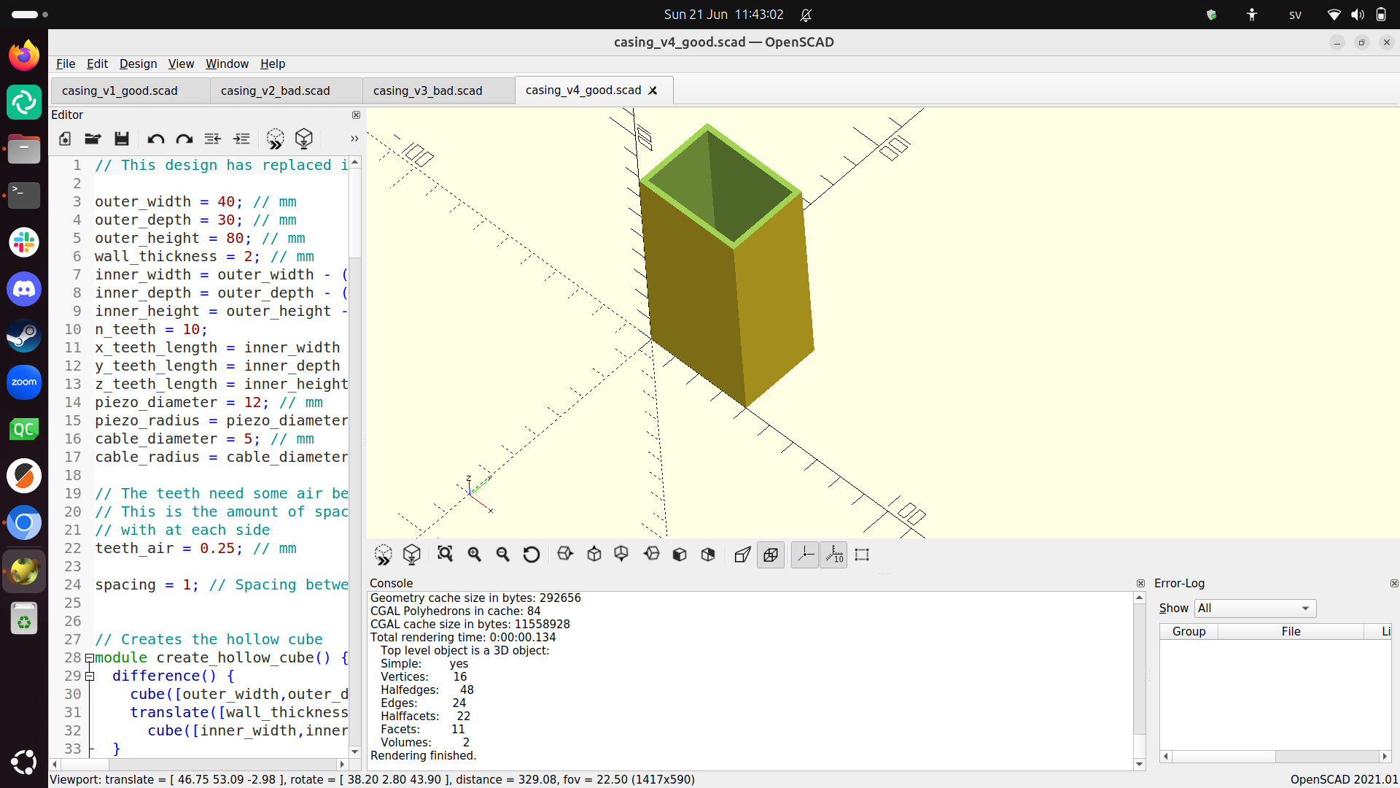
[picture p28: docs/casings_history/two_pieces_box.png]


However, how to connect the lid?

I decided to start using a screw-on approach. Then, I realized,
that I might as well make the clock spherical: it fits the theme better.

This is how I landed on the final design.

## Sphere

A spherical design for a pi clock felt like a good fit.
I wanted to have the sphere consists out of two half-spheres
that can be screwed together.

First, I designed the screw,
as I wanted to make sure that it could work:

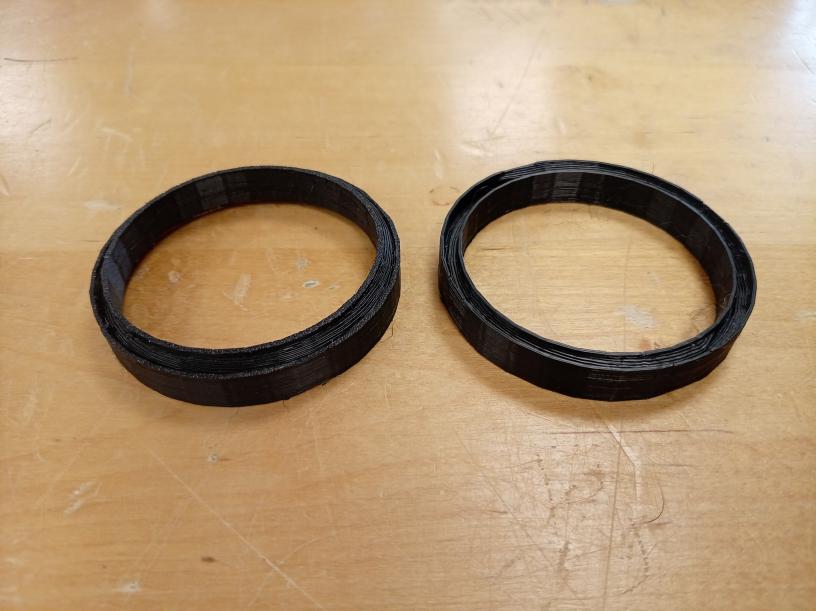
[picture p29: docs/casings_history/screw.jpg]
My screw prints


The screw at the left did not work properly,
with an air gap of 1 millimeter.
The screw at the right had an air gap of 2 millimeter
and worked great!

Then I printed my first sphere:

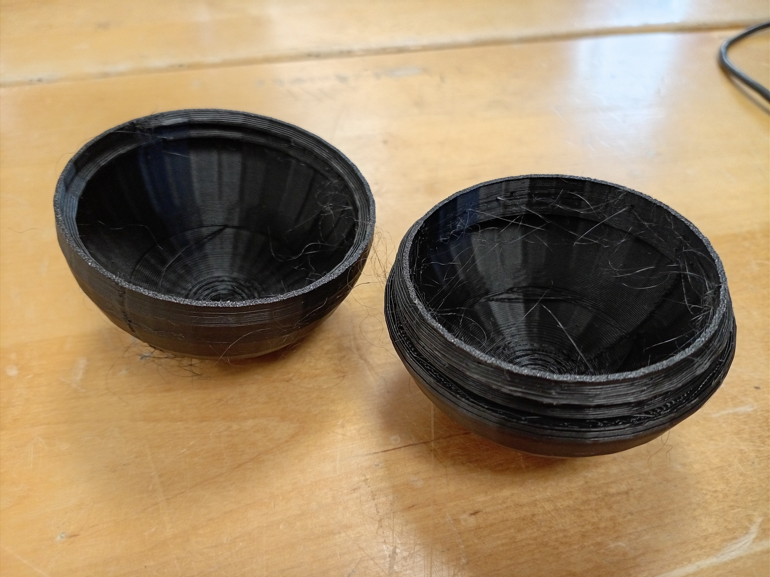
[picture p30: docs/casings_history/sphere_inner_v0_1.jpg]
My first sphere print, inside


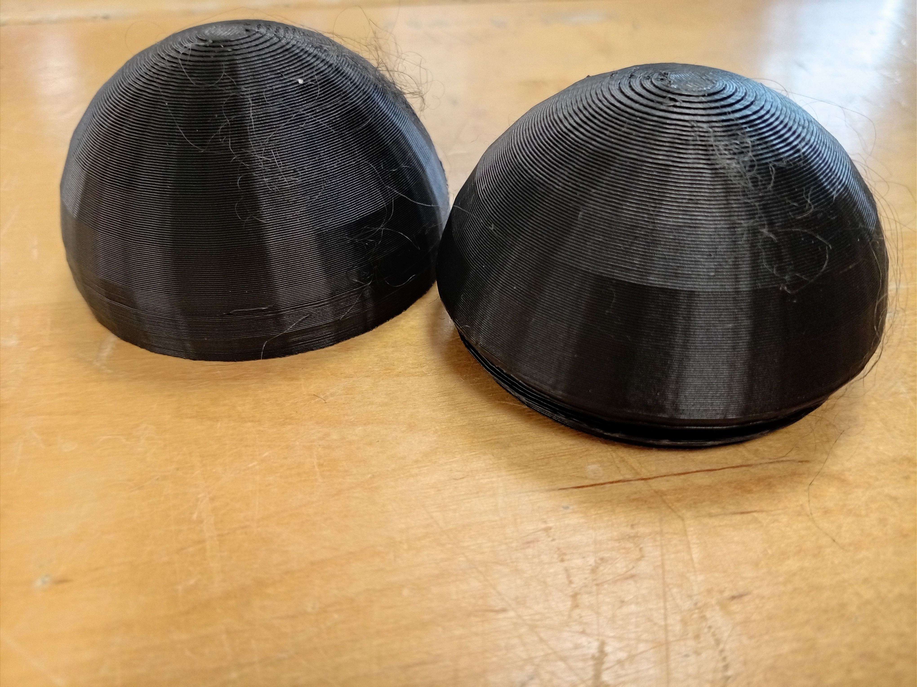
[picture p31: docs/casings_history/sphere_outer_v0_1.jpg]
My first sphere print, outside


It worked great!

My first design had a structural weakness:
the ring that connected the bolt with the outer sphere
was too thin and needed scaffolding.

I decided to make both the bolt and nut to extend down/up the entire
half-sphere, making it sturdier and reduce scaffolds.

Sphere v0.2

The PCB fit the casing:

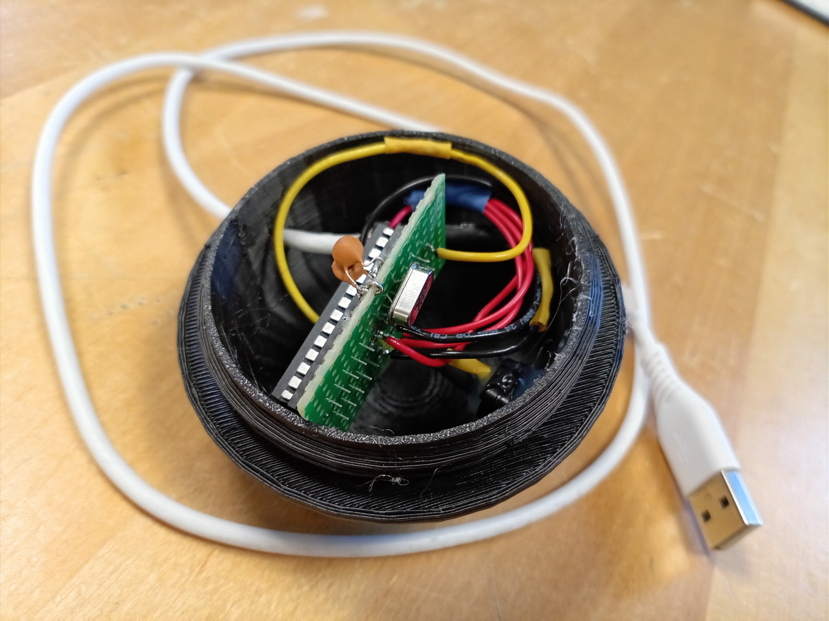
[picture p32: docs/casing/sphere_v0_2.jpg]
Sphere v0.2, with electronics in it


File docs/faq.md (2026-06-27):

# FAQ

## What does the clock do?

It beeps at pi o'clock (i.e. 3:14 PM),
for a bit longer than three seconds,
at a frequency a bit higher than 3 kHz.

## How to set the time?

Unplug its power. Plug it in at pi o'clock.

## How to read the time?

You cannot. It only beeps at pi o'clock.

## How to power the Minimal Pi Clock

The Minimal Pi Clock can be powered by
plugging the USB cable into most machines an USB ports,
such as laptops.

## How to make a casing for a Minimal Pi Clock

My favorite casing for the Mininal Pi Clock
can be found at [the 'casing' page](casing/README.md).

## How expensive is the Minimal Pi Clock?

About twenty euros in total.

## Can I make a Minimal Pi Clock myself?

Yes, it is rather easy. All schematics and code are on this website.

## Will you make a Minimal Pi Clock for me?

No. But I can help. Or try your local hacker- or makerspace.
One example is
[my 'Build a bare-bone machine' workshop](https://richelbilderbeek.github.io/build_bare_bone_arduino_machine_workshop/)
at [the Uppsala Makerspace.](https://www.uppsalamakerspace.se/).

## Do you think using an ATmega328P chip is overkill here?

Yes.

I decided to use it anyways, as I have access to mostly Arduino Uno's.

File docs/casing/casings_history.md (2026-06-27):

# Casing's history

Here is the history of [the casing](README.md)
used in this machine.

## Six pieces box

The 'six pieces box' was my first idea
and my first real casing design, in OpenSCAD:

- [six_pieces_box.scad](six_pieces_box.scad)

Six pieces box

I wanted a design without scaffolding, hence I opted
to glue to pieces together.

However, I was unhappy with this design, as it involved too much glue
and the glue available to me was not strong enough.

I realized that
I can instead go for an open box design, where only a
lid needs to be conneced to the box-except-lid.
I decided to transition to this two pieces box design.

## Two pieces box

Instead of glueing together the six pieces,
I realized I could print 5 out of 6 pieces as one single piece
without scaffolding.

I first tried to create such a two pieces box
using Claude. It did not work out well:

- [transition_1.scad](transition_1.scad)

Transition 1

- [transition_2.scad](transition_2.scad)

Transition 2

Realizing Claude does not understand OpenSCAD well enough,
I designed part of this design hand instead.

- [two_pieces_box.scad](two_pieces_box.scad)



However, how to connect the lid?

I decided to start using a screw-on approach. Then, I realized,
that I might as well make the clock spherical: it fits the theme better.

This is how I landed on the final design.

## Sphere

A spherical design for a pi clock felt like a good fit.
I wanted to have the sphere consists out of two half-spheres
that can be screwed together.

It worked great!

My first design had a structural weakness:
the ring that connected the bolt with the outer sphere
was too thin and needed scaffolding.

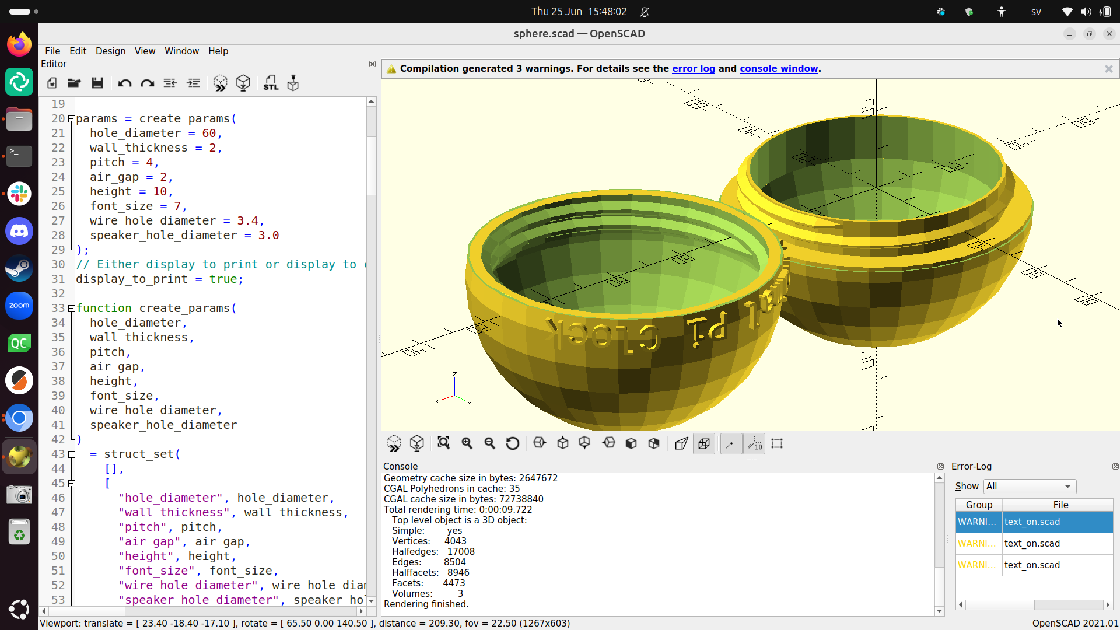
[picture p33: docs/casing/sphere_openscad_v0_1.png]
Sphere v0.1


I decided to make both the bolt and nut to extend down/up the entire
half-sphere, making it sturdier and reduce scaffolds.

Sphere v0.2

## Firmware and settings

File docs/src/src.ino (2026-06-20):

/*

  Minimal Pi Clock
  (C) 2015 Richel Bilderbeek

2015-07-05: v.1.0: Initial version
2015-08-21: v.1.1: Added beep if A0 is connected to GND at startup
2019-07-19: v.1.2: Always beep at startup
2019-11-03: v.1.3: Plug in at Pi o'clock instead of at midnight
2026-06-20: v.1.4: Remove TimeLib

Piezo:
  
    8              GND
    |  +--------+  |
    +--+   P    +--+
       +--------+

  8: piezo pin
  P: Piezo
  GND: Arduino GND pin

*/

const int pin_piezo = 8; //The pin connected to the piezo

void beep()
{
  const int frequency_hz = 3142;
  const int duration_msec = 3142;
  tone(pin_piezo, frequency_hz, duration_msec);
}

void setup() 
{
  pinMode(pin_piezo, OUTPUT);
}

void loop() 
{
  while (1)
  {
    beep();

    for (int h = 0; h = 23; ++h)
    {
      for (int m = 0; m = 60; ++m)
      {
        delay(1000);
      }    
    }
    for (int m = 0; m = 56; ++m)
    {
      delay(1000);
    }
    delay(4000 - 3142);
  }
}

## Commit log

2017-04-13 Moved from PiClock
    [MinimalPiClock.fzz]
2017-04-13 Added FAQ [skip ci]
    [src.ino]
2019-07-19 Fixed schematic
    [MinimalPiClock.fzz]
2019-07-19 Show schematic
2019-07-19 Always beep at startup
    [MinimalPiClock.fzz]
2026-06-21 Add casing
    [casing_v1_good.scad, casing_v2_bad.scad, casing_v3_bad.scad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]
2026-06-21 Make MkDocs
    [MinimalPiClock.fzz, casing_v1_good.scad, casing_v2_bad.scad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]
2026-06-21 Use correct folder name
    [minimal_pi_clock.fzz]
2026-06-21 Show casing
    [six_pieces_box.scad, transition_1.scad, transition_2.scad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]
2026-06-21 Progress casing
    [sphere.scad]
2026-06-22 Add BOM
2026-06-22 Improve schematic
    [minimal_pi_clock.fzz]
2026-06-24 Connector is getting good
    [sphere.scad]
2026-06-24 Ready for testing
    [sphere.scad]
2026-06-24 Do not mirror: it makes the thread have the same winding (i.e. both clock/counterclock-wise)
    [sphere.scad]
2026-06-24 Scaffolding on the outside
    [sphere.scad]
2026-06-25 Can use params
    [sphere.scad]
2026-06-25 Use params
    [sphere.scad]
2026-06-25 Draw lower half using struct
    [sphere.scad]
2026-06-25 Draw upper sphere using struct
    [sphere.scad]
2026-06-25 Draw casing using structs
    [sphere.scad]
2026-06-25 Add todo
    [sphere.scad]
2026-06-26 Use thicker walls
    [sphere.scad]
2026-06-26 Sturdier bolt
    [sphere.scad]
2026-06-26 Bolt and nut have no scaffolding
    [sphere.scad]
2026-06-26 Make the outsides be up; only scaffolding marks on the inside
    [sphere.scad]
2026-06-26 Put holes at the right spot
    [sphere.scad]
2026-06-26 Cleanup code
    [sphere.scad]
2026-06-26 Improve displayal
    [sphere.scad]
2026-06-27 Better doc
    [sphere.scad]
2026-06-27 Own folder for casing history
    [six_pieces_box.scad, transition_1.scad, transition_2.scad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]
2026-06-27 Fix Markdown
    [sphere.scad]
